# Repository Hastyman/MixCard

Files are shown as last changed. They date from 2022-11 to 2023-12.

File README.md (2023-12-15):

# MixCard
Three channel synth mixer in convenient business card sized format.
Card was created as part of a series from creators participating in the
www.synthcard.com project.

This is my take on a Synth DIY mixer --
It's a mix circuit based 
on the NPN Transistor. Credit and thanks for
the original schematic goes to NJ Ramsden. 
Check out his Insta @Synthnerd

Schematics under /Synthcard_Mixer_KiCad and panel design under /Inkscape_Files

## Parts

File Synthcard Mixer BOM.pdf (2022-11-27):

# Synthcard Mixer

Date: | Sunday, November 27, 2022 at 09:25:31 AM
Tool: | Eeschema (6.0.9-0)
Component Count: | 27
Ref | Qnty | Value | Manufacturer Part Number | Description | Cmp name | Footprint
C1, C2, C3, | 3 | 330nF | MMK5334K50J01L4BULK | Unpolarized capacitor | C | Capacitor_THT:C_Rect_L7.0mm_W2.0mm_P5.00m m
C4, | 1 | 150nF | MMK5154K50J01L4BULK | Unpolarized capacitor | C | Capacitor_THT:C_Rect_L7.0mm_W2.0mm_P5.00m m
C5, C6, | 2 | 10uF | 25MH510MEFC5X5 | Polarized capacitor, small US symbol | C_Polarized_Small _US | Capacitor_THT:CP_Radial_D5.0mm_P2.00mm
D1, | 1 | 1N4001 | 1N4001 | 50V 1A General Purpose Rectifier Diode, DO-41 | 1N4001 | Diode_THT:D_DO-41_SOD81_P10.16mm_Horizont al
D2, | 1 | 5MM LED | LTH5MM12VFR4100 | Light emitting diode | LED | LED_THT:LED_D5.0mm
J1, | 1 | Input 1 | PJ-3001F | Audio Jack, 2 Poles (Mono / TS), Switched T Pole (Normalling) | AudioJack2_Switc hT | Connector_Audio:Jack_3.5mm_QingPu_WQP-PJ398SM_Vertical_CircularHoles
J2, | 1 | Input 2 | PJ-3001F | Audio Jack, 2 Poles (Mono / TS), Switched T Pole (Normalling) | AudioJack2_Switc hT | Connector_Audio:Jack_3.5mm_QingPu_WQP-PJ398SM_Vertical_CircularHoles
J3, | 1 | Input 3 | PJ-3001F | Audio Jack, 2 Poles (Mono / TS), Switched T Pole (Normalling) | AudioJack2_Switc hT | Connector_Audio:Jack_3.5mm_QingPu_WQP-PJ398SM_Vertical_CircularHoles
J4, | 1 | Output | PJ-3001F | Audio Jack, 2 Poles (Mono / TS), Switched T Pole (Normalling) | AudioJack2_Switc hT | Connector_Audio:Jack_3.5mm_QingPu_WQP-PJ398SM_Vertical_CircularHoles
J5, | 1 | Conn_01x02 | 22-28-4242g | Generic connector, single row, 01x02 | Conn_01x02 | Connector_PinHeader_2.54mm:PinHeader_1x02_P 2.54mm_Vertical
Q1, | 1 | 2N3904 | 2N3904 | 0.2A Ic, 40V Vce, Small Signal NPN Transistor, TO-92 | 2N3904 | Package_TO_SOT_THT:TO-92L_HandSolder
R1, R2, R3, | 3 | 100k | CMF50100K00FHEB | Resistor, small US symbol | R_Small_US | Resistor_THT:R_Axial_DIN0204_L3.6mm_D1.6mm _P5.08mm_Horizontal
R4, | 1 | 200k | CMF50200K00FHEB | Resistor, small US symbol | R_Small_US | Resistor_THT:R_Axial_DIN0204_L3.6mm_D1.6mm _P5.08mm_Horizontal
R5, | 1 | 1M | CMF501M0000FHEK | Resistor, small US symbol | R_Small_US | Resistor_THT:R_Axial_DIN0204_L3.6mm_D1.6mm _P5.08mm_Horizontal
R6, | 1 | 4k75 | CMF504K7500FHEB | Resistor, small US symbol | R_Small_US | Resistor_THT:R_Axial_DIN0204_L3.6mm_D1.6mm _P5.08mm_Horizontal
R7, | 1 | 10k | CMF5010K000FHEB | Resistor, small US symbol | R_Small_US | Resistor_THT:R_Axial_DIN0204_L3.6mm_D1.6mm _P5.08mm_Horizontal
R8, | 1 | 1k | CMF501K0000FHEB | Resistor, small US symbol | R_Small_US | Resistor_THT:R_Axial_DIN0204_L3.6mm_D1.6mm _P5.08mm_Horizontal
R9, | 1 | 680R | CMF50681R00FHEB | Resistor, small US symbol | R_Small_US | Resistor_THT:R_Axial_DIN0204_L3.6mm_D1.6mm _P5.08mm_Horizontal
RV1, RV2, RV3, | 3 | 100k | RV09AF-40-20K-A100K | Potentiometer, US symbol | R_Potentiometer_U S | Potentiometer_THT:Potentiometer_Alps_RK09K_Si ngle_Vertical

1

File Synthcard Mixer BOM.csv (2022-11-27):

Synthcard Mixer
Tool: | Eeschema (6.0.9-0)
Component Count: | 27
Ref | Qnty | Value | Manufacturer Part Number | Description | Cmp name | Footprint
C1, C2, C3, | 3 | 330nF | MMK5334K50J01L4BULK | Unpolarized capacitor | C | Capacitor_THT:C_Rect_L7.0mm_W2.0mm_P5.00mm
C4, | 1 | 150nF | MMK5154K50J01L4BULK | Unpolarized capacitor | C | Capacitor_THT:C_Rect_L7.0mm_W2.0mm_P5.00mm
C5, C6, | 2 | 10uF | 25MH510MEFC5X5 | Polarized capacitor, small US symbol | C_Polarized_Small_US | Capacitor_THT:CP_Radial_D5.0mm_P2.00mm
D1, | 1 | 1N4001 | 1N4001 | 50V 1A General Purpose Rectifier Diode, DO-41 | 1N4001 | Diode_THT:D_DO-41_SOD81_P10.16mm_Horizontal
D2, | 1 | 5MM LED | LTH5MM12VFR4100 | Light emitting diode | LED | LED_THT:LED_D5.0mm
J1, | 1 | Input 1 | PJ-3001F | Audio Jack, 2 Poles (Mono / TS), Switched T Pole (Normalling) | AudioJack2_SwitchT | Connector_Audio:Jack_3.5mm_QingPu_WQP-PJ398SM_Vertical_CircularHoles
J2, | 1 | Input 2 | PJ-3001F | Audio Jack, 2 Poles (Mono / TS), Switched T Pole (Normalling) | AudioJack2_SwitchT | Connector_Audio:Jack_3.5mm_QingPu_WQP-PJ398SM_Vertical_CircularHoles
J3, | 1 | Input 3 | PJ-3001F | Audio Jack, 2 Poles (Mono / TS), Switched T Pole (Normalling) | AudioJack2_SwitchT | Connector_Audio:Jack_3.5mm_QingPu_WQP-PJ398SM_Vertical_CircularHoles
J4, | 1 | Output | PJ-3001F | Audio Jack, 2 Poles (Mono / TS), Switched T Pole (Normalling) | AudioJack2_SwitchT | Connector_Audio:Jack_3.5mm_QingPu_WQP-PJ398SM_Vertical_CircularHoles
J5, | 1 | Conn_01x02 | 22-28-4242g | Generic connector, single row, 01x02 | Conn_01x02 | Connector_PinHeader_2.54mm:PinHeader_1x02_P2.54mm_Vertical
Q1, | 1 | 2N3904 | 2N3904 | 0.2A Ic, 40V Vce, Small Signal NPN Transistor, TO-92 | 2N3904 | Package_TO_SOT_THT:TO-92L_HandSolder
R1, R2, R3, | 3 | 100k | CMF50100K00FHEB | Resistor, small US symbol | R_Small_US | Resistor_THT:R_Axial_DIN0204_L3.6mm_D1.6mm_P5.08mm_Horizontal
R4, | 1 | 200k | CMF50200K00FHEB | Resistor, small US symbol | R_Small_US | Resistor_THT:R_Axial_DIN0204_L3.6mm_D1.6mm_P5.08mm_Horizontal
R5, | 1 | 1M | CMF501M0000FHEK | Resistor, small US symbol | R_Small_US | Resistor_THT:R_Axial_DIN0204_L3.6mm_D1.6mm_P5.08mm_Horizontal
R6, | 1 | 4k75 | CMF504K7500FHEB | Resistor, small US symbol | R_Small_US | Resistor_THT:R_Axial_DIN0204_L3.6mm_D1.6mm_P5.08mm_Horizontal
R7, | 1 | 10k | CMF5010K000FHEB | Resistor, small US symbol | R_Small_US | Resistor_THT:R_Axial_DIN0204_L3.6mm_D1.6mm_P5.08mm_Horizontal
R8, | 1 | 1k | CMF501K0000FHEB | Resistor, small US symbol | R_Small_US | Resistor_THT:R_Axial_DIN0204_L3.6mm_D1.6mm_P5.08mm_Horizontal
R9, | 1 | 680R | CMF50681R00FHEB | Resistor, small US symbol | R_Small_US | Resistor_THT:R_Axial_DIN0204_L3.6mm_D1.6mm_P5.08mm_Horizontal
RV1, RV2, RV3, | 3 | 100k | RV09AF-40-20K-A100K | Potentiometer, US symbol | R_Potentiometer_US | Potentiometer_THT:Potentiometer_Alps_RK09K_Single_Vertical

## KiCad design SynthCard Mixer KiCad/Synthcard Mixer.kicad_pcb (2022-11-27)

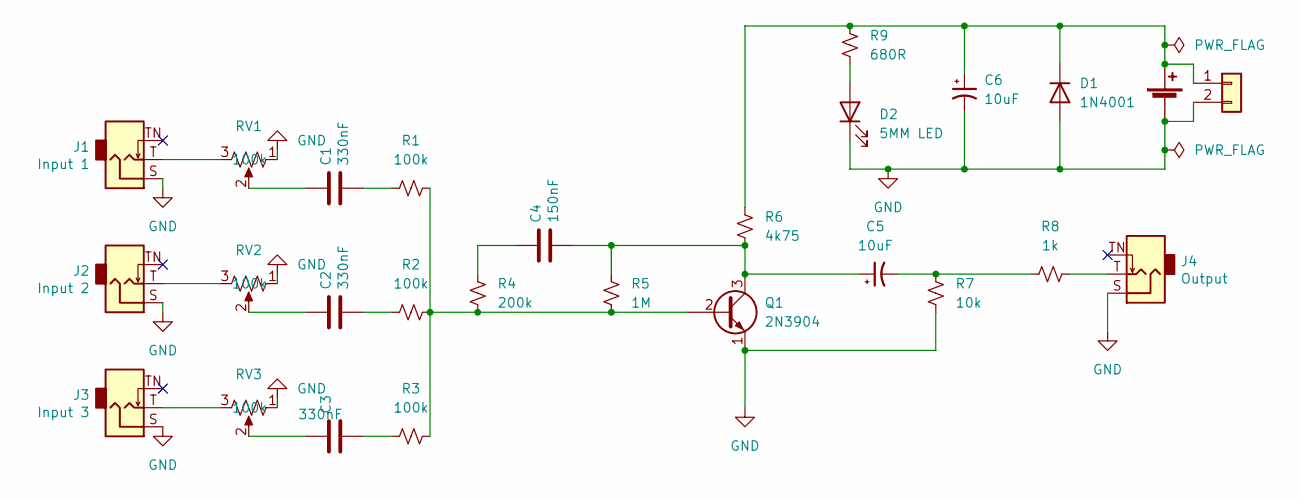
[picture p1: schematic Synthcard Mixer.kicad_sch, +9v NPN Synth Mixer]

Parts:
BT1: Battery_Cell
C1, C2, C3: 330nF; C_Rect_L7.0mm_W2.0mm_P5.00mm; Manufacturers Part Numb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 MMK5334K50J01L4BULK
C4: 150nF; C_Rect_L7.0mm_W2.0mm_P5.00mm; Manufacturers Part Numb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 MMK5154K50J01L4BULK
C5, C6: 10uF; CP_Radial_D5.0mm_P2.00mm
D1: 1N4001; D_DO-41_SOD81_P10.16mm_Horizontal
D2: 5MM LED; LED_D5.0mm
J1: Input 1; Jack_3.5mm_QingPu_WQP-PJ398SM_Vertical_CircularHoles; Manufacturers Part Numb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 PJ-3001F
J2: Input 2; Jack_3.5mm_QingPu_WQP-PJ398SM_Vertical_CircularHoles; Manufacturers Part Numb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 PJ-3001F
J3: Input 3; Jack_3.5mm_QingPu_WQP-PJ398SM_Vertical_CircularHoles; Manufacturers Part Numb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 PJ-3001F
J4: Output; Jack_3.5mm_QingPu_WQP-PJ398SM_Vertical_CircularHoles; Manufacturers Part Numb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 PJ-3001F
J5: Conn_01x02; PinHeader_1x02_P2.54mm_Vertical
Q1: 2N3904; TO-92L_HandSolder
R1, R2, R3: 100k; R_Axial_DIN0204_L3.6mm_D1.6mm_P5.08mm_Horizontal
R4: 200k; R_Axial_DIN0204_L3.6mm_D1.6mm_P5.08mm_Horizontal
R5: 1M; R_Axial_DIN0204_L3.6mm_D1.6mm_P5.08mm_Horizontal
R6: 4k75; R_Axial_DIN0204_L3.6mm_D1.6mm_P5.08mm_Horizontal
R7: 10k; R_Axial_DIN0204_L3.6mm_D1.6mm_P5.08mm_Horizontal
R8: 1k; R_Axial_DIN0204_L3.6mm_D1.6mm_P5.08mm_Horizontal
R9: 680R; R_Axial_DIN0204_L3.6mm_D1.6mm_P5.08mm_Horizontal
RV1, RV2, RV3: 100k; Potentiometer_Alps_RK09K_Single_Vertical; Manufacturers Part Numb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 RV09AF-40-20K-A100K

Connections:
GND: BT1.2 (-), C6.2, D1.2 (A), D2.1 (K), J1.S, J2.S, J3.S, J4.S, J5.2, Q1.1 (E), R7.2, RV1.1, RV2.1, RV3.1
unnamed: BT1.1 (+), C6.1, D1.1 (K), J5.1, R6.1, R9.1
unnamed: C1.1, RV1.2
unnamed: C1.2, R1.1
unnamed: C2.1, RV2.2
unnamed: C2.2, R2.1
unnamed: C3.1, RV3.2
unnamed: C3.2, R3.1
unnamed: C4.1, R4.1
unnamed: C4.2, C5.1, Q1.3 (C), R5.1, R6.2
unnamed: C5.2, R7.1, R8.1
unnamed: D2.2 (A), R9.2
unnamed: J1.T, RV1.3
unnamed: J2.T, RV2.3
unnamed: J3.T, RV3.3
unnamed: J4.T, R8.2
unnamed: Q1.2 (B), R1.2, R2.2, R3.2, R4.2, R5.2

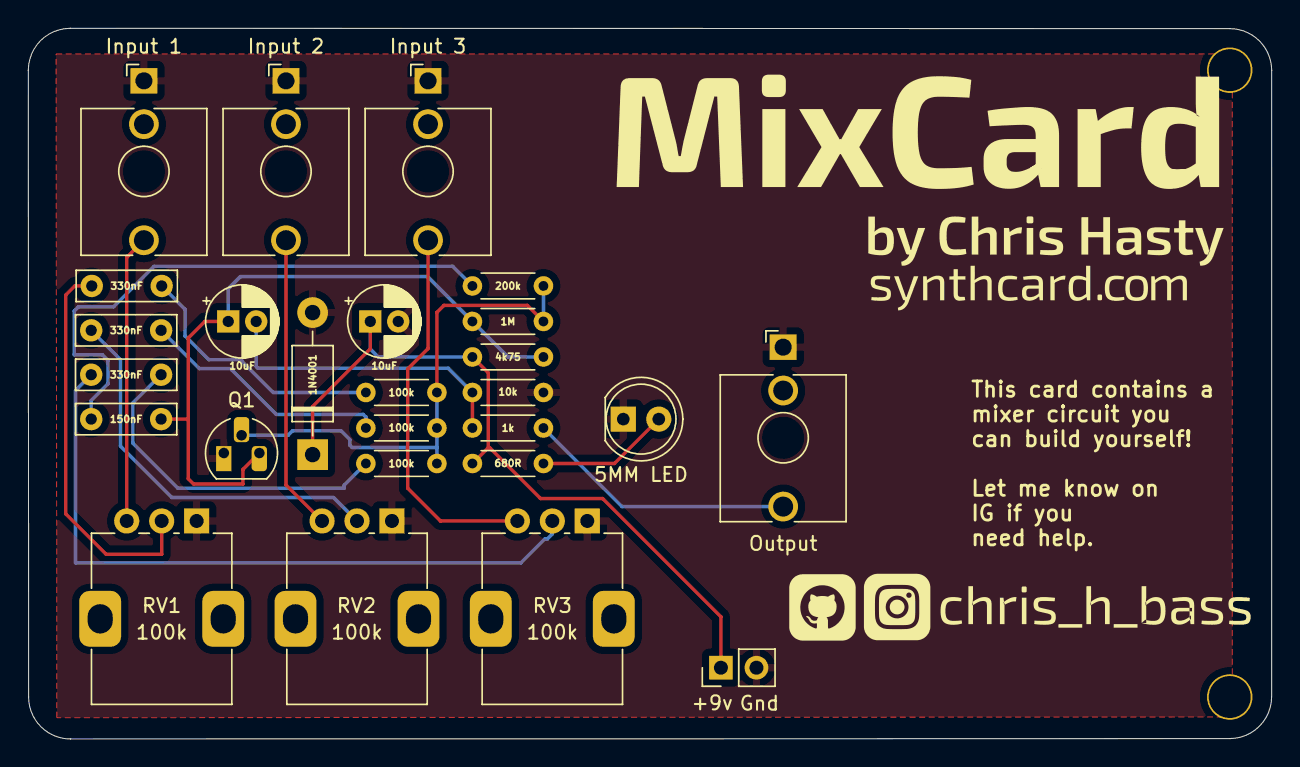
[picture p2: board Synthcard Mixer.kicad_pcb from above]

Board: 2 copper layers, 88.9 x 50.8 mm, 26 parts (0 on the bottom side), 17 nets.

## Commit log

2022-11-27 Addition of KiCad files
    [Synthcard Mixer.kicad_pcb, Synthcard Mixer.kicad_sch]
2022-11-27 Imported BOM as CSV and PDF
    [Synthcard Mixer BOM.csv]
2022-11-27 Update Synthcard Mixer BOM.csv
    [Synthcard Mixer BOM.csv]
